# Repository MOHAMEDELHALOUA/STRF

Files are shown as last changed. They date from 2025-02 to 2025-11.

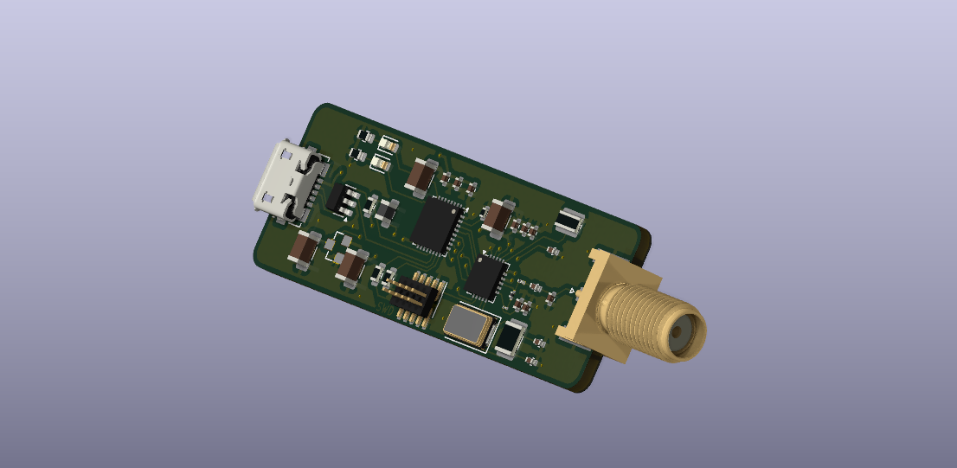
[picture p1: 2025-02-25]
STRF/finaleProduct/STRF.png

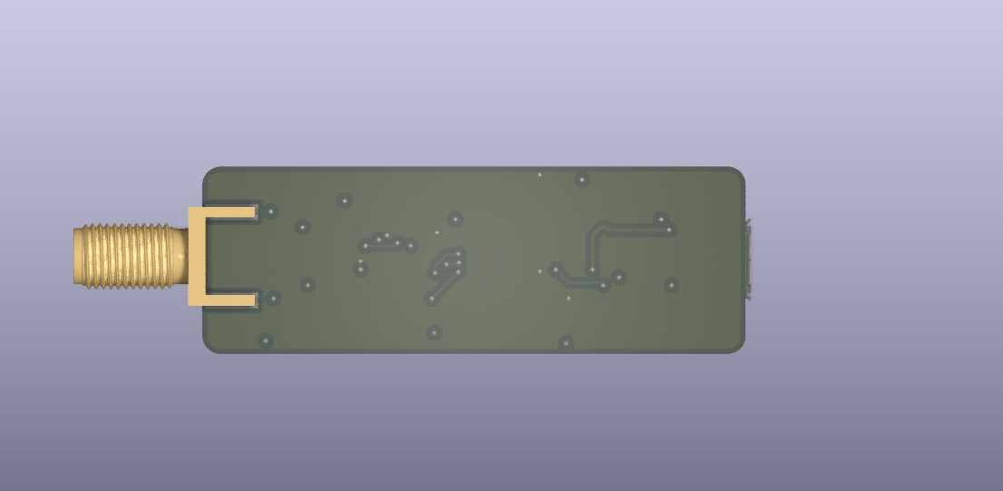
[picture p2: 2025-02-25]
STRF/finaleProduct/STRF_back.png

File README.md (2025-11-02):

# STRF
The board incorporates an STM32 microcontroller, an RF transceiver, an antenna interface, and a micro-USB full-speed interface. It is designed for various projects, such as logging data from a robot with RF capabilities. The STM32 serves as a link between the RF transceiver and a host computer via USB, and the design emphasizes compactness, measuring 15mm in height and 40mm in length.

STRF
STRF_front
STRF_back
layout1
layout2
layout3
schematic

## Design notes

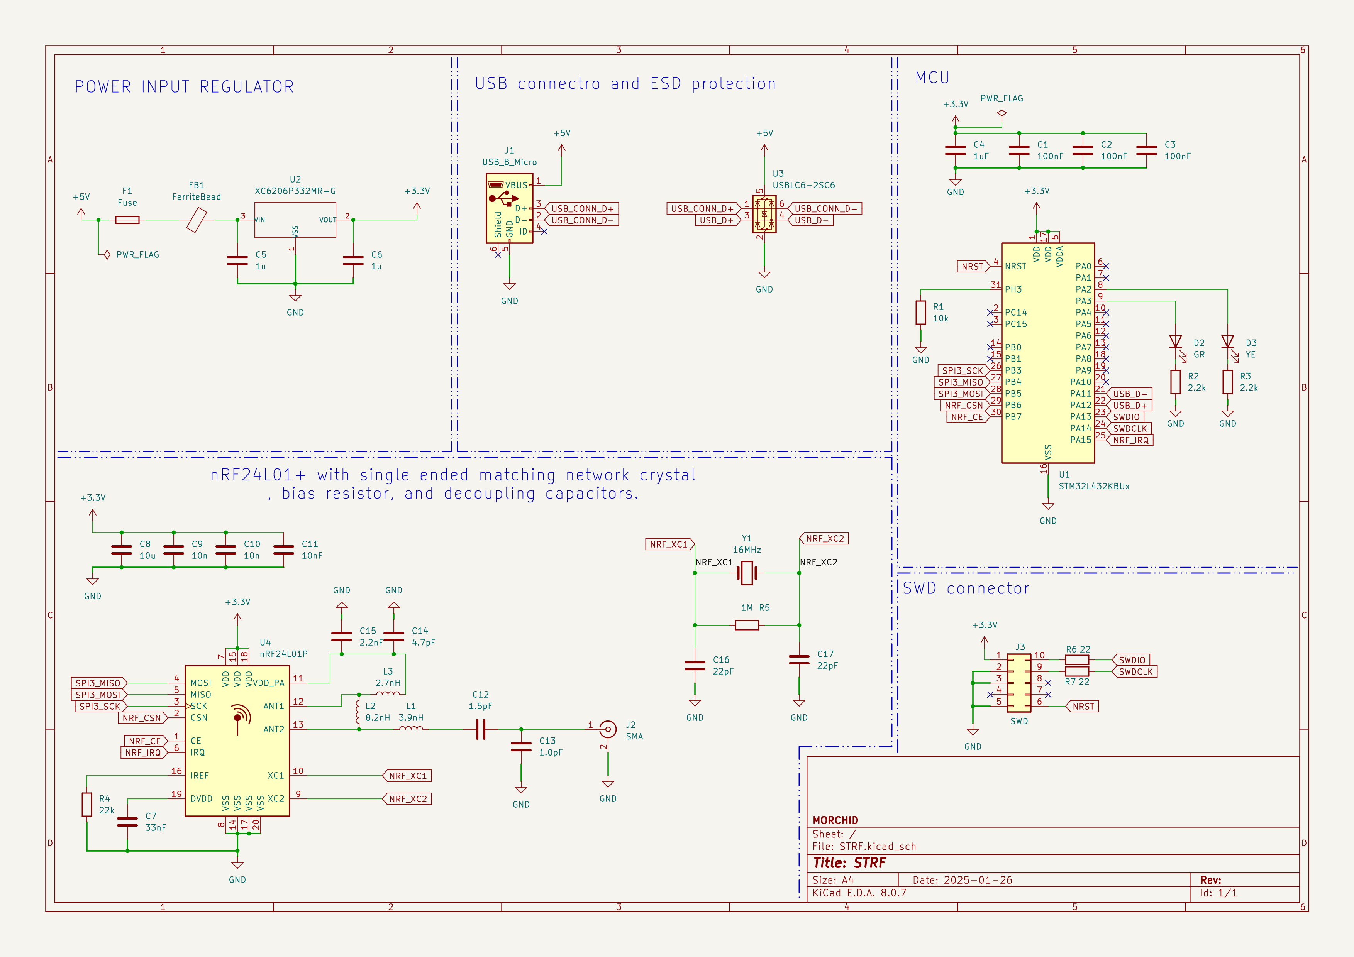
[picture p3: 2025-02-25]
STRF/finaleProduct/schematic.png

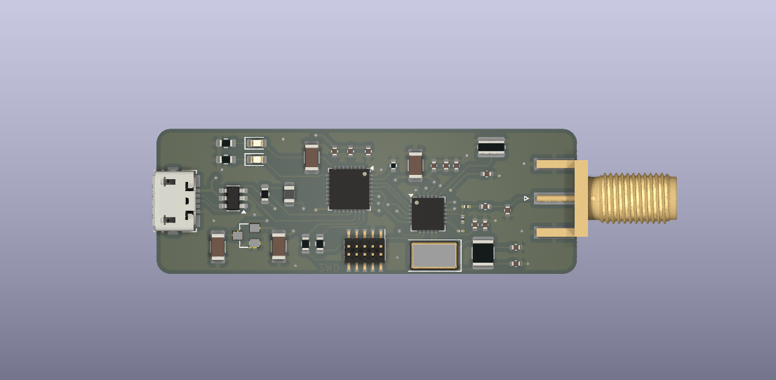
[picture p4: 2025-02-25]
STRF/finaleProduct/STRF_front.png

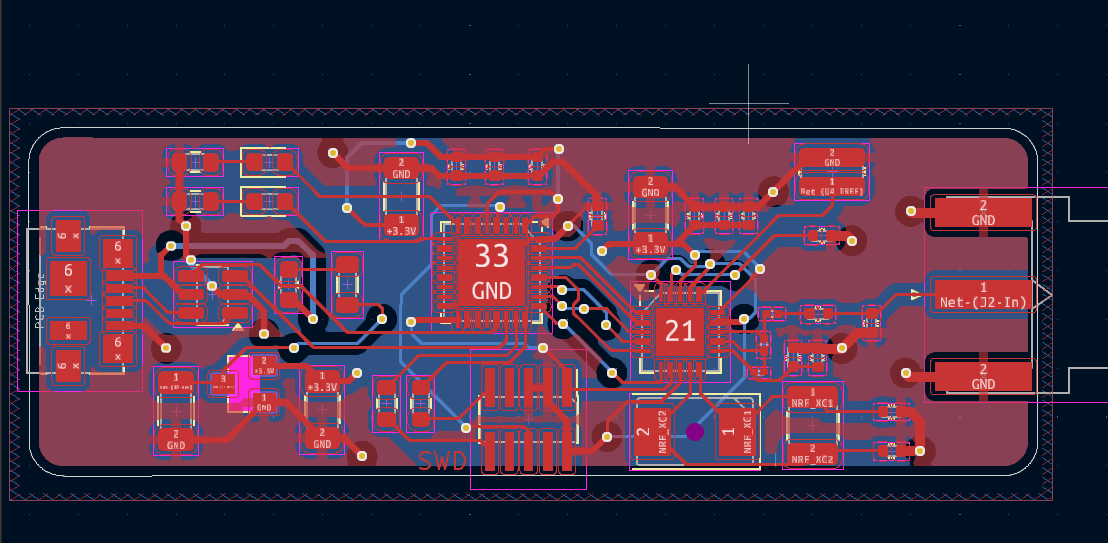
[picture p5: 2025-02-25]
STRF/finaleProduct/layout2.png

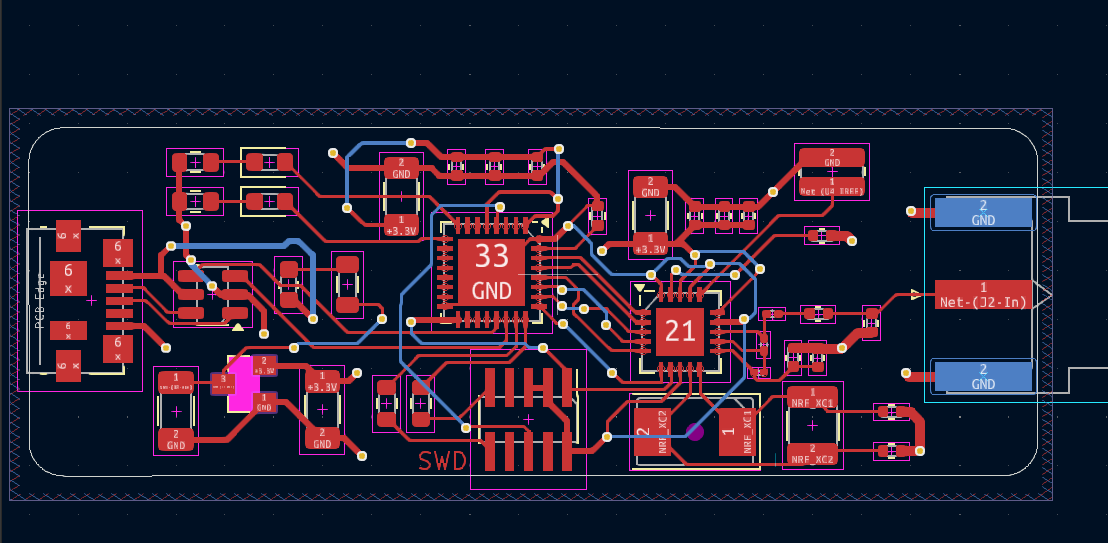
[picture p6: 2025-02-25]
STRF/finaleProduct/layout1.png

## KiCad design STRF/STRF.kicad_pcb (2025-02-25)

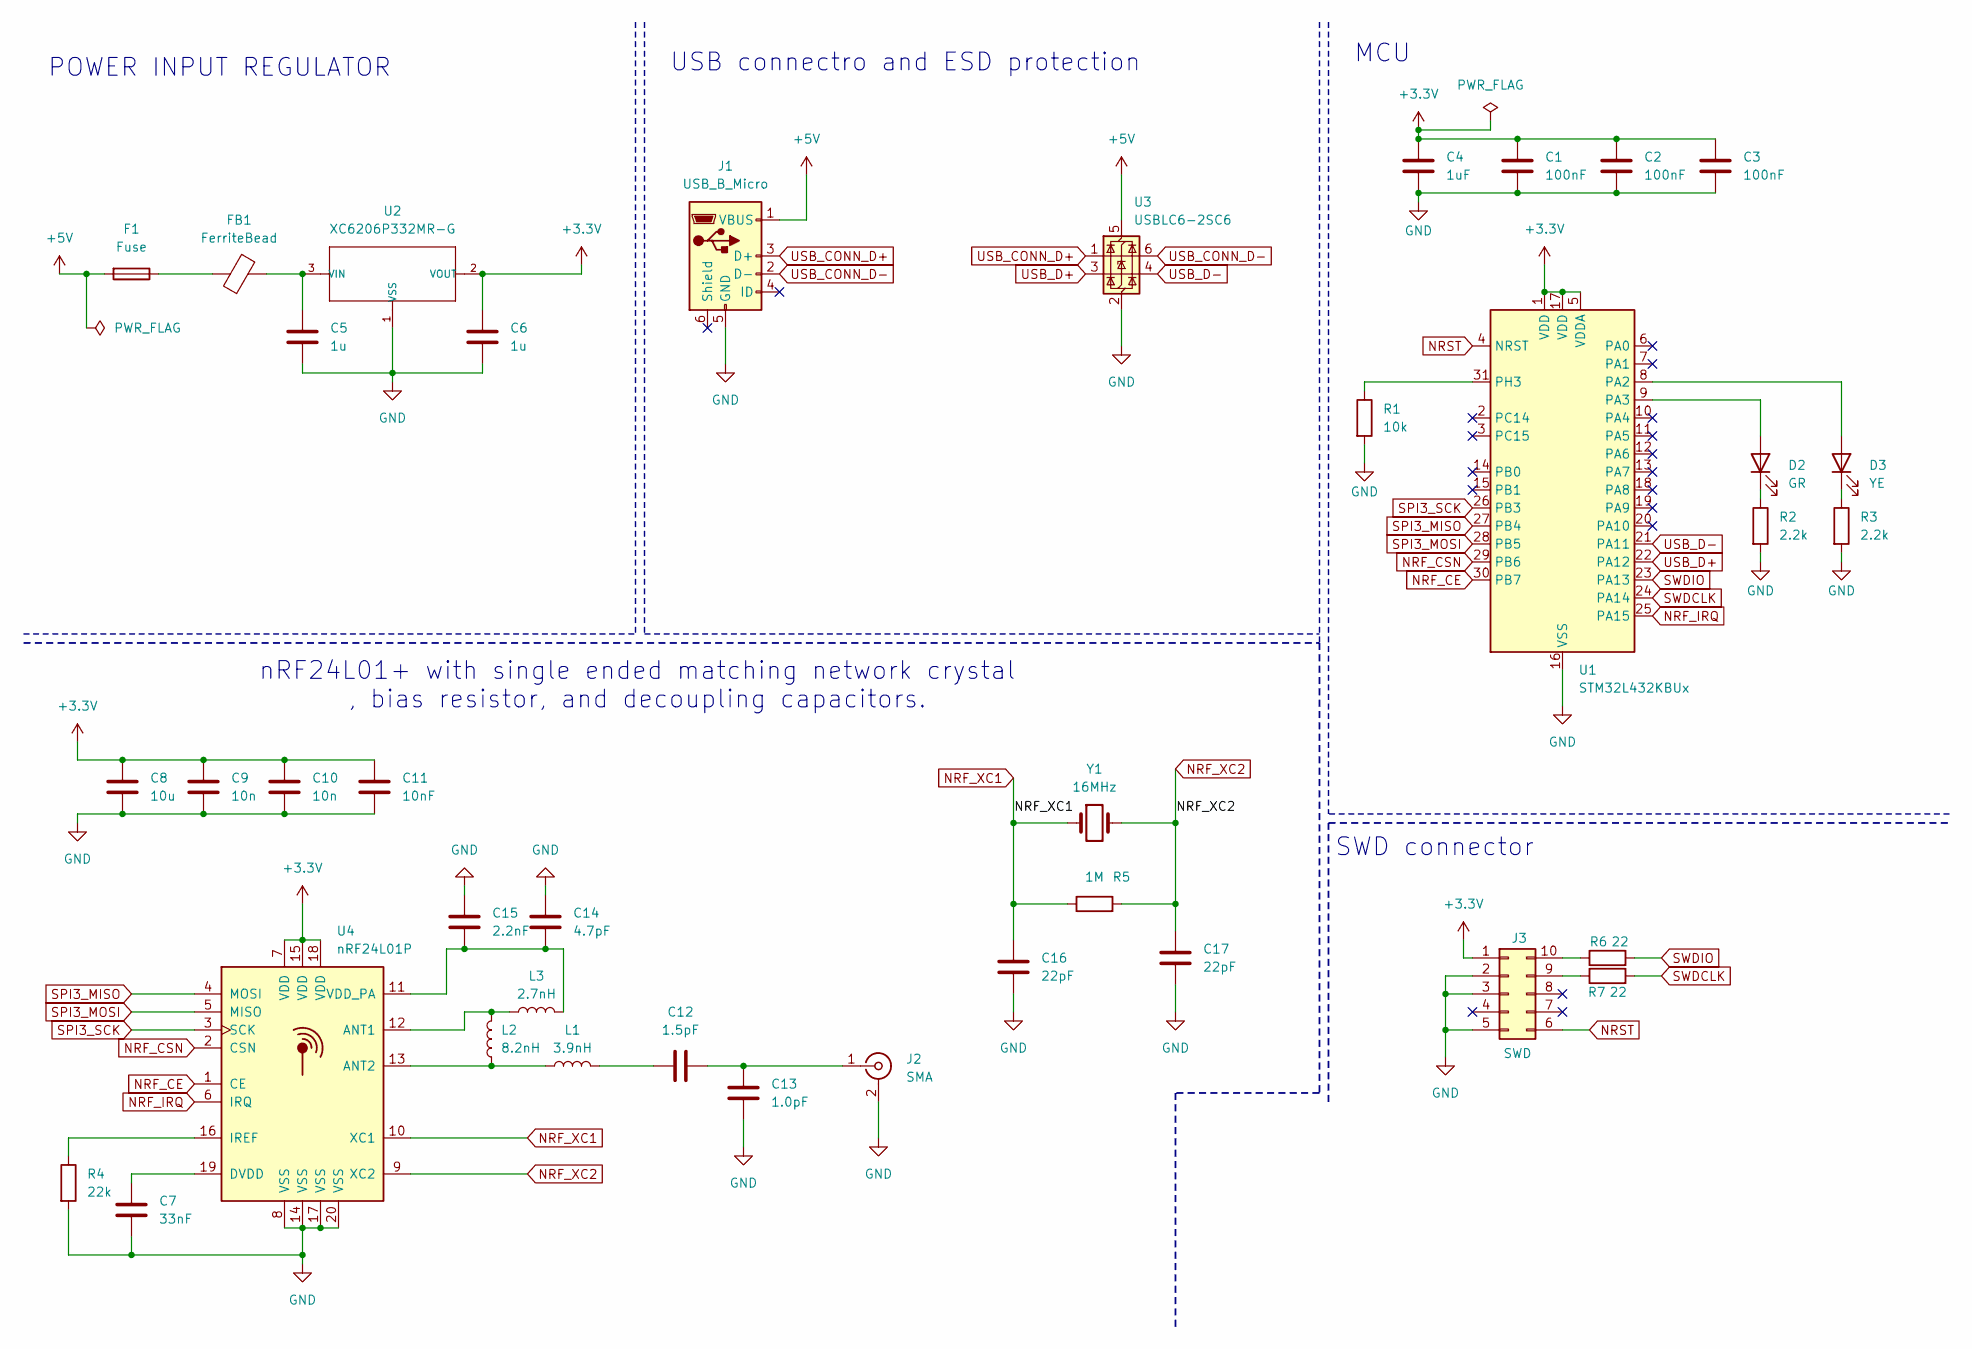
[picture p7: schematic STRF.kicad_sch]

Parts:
C1, C2, C3: 100nF; C_0402_1005Metric
C4: 1uF; C_1206_3216Metric
C5, C6: 1u; C_1206_3216Metric
C7: 33nF; C_0402_1005Metric
C8: 10u; C_1206_3216Metric
C9, C10: 10n; C_0402_1005Metric
C11: 10nF; C_0402_1005Metric
C12: 1.5pF; C_0402_1005Metric
C13: 1.0pF; C_0402_1005Metric
C14: 4.7pF; C_0402_1005Metric
C15: 2.2nF; C_0402_1005Metric
C16, C17: 22pF; C_0402_1005Metric
D2: GR; LED_0603_1608Metric
D3: YE; LED_0603_1608Metric
F1: Fuse; Fuse_0603_1608Metric
FB1: FerriteBead; L_0805_2012Metric
J1: USB_B_Micro; USB_Micro-B_Molex_47346-0001
J2: SMA; SMA_Amphenol_132289_EdgeMount
J3: SWD; PinHeader_2x05_P1.00mm_Vertical_SMD
L1: 3.9nH; L_0201_0603Metric
L2: 8.2nH; L_0201_0603Metric
L3: 2.7nH; L_01005_0402Metric
R1: 10k; R_0402_1005Metric
R2, R3: 2.2k; R_0603_1608Metric
R4: 22k; R_0612_1632Metric
R5: 1M; R_1210_3225Metric
R6, R7: 22; R_0603_1608Metric
U1: STM32L432KBUx; QFN-32-1EP_5x5mm_P0.5mm_EP3.45x3.45mm
U2: XC6206P332MR-G; SOT-23; MPN XC6206P332MR-G
U3: USBLC6-2SC6; SOT-23-6
U4: nRF24L01P; QFN-20-1EP_4x4mm_P0.5mm_EP2.5x2.5mm
Y1: 16MHz; Crystal_SMD_0603-2Pin_6.0x3.5mm

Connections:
+3.3V: C1.1, C2.1, C3.1, C4.1, C6.1, C8.1, C9.1, C10.1, C11.1, J3.1, U1.1 (VDD), U1.5 (VDDA), U1.17 (VDD), U2.2 (VOUT), U4.7 (VDD), U4.15 (VDD), U4.18 (VDD)
+5V: F1.2, J1.1 (VBUS), U3.5 (VBUS)
GND: C1.2, C2.2, C3.2, C4.2, C5.2, C6.2, C7.2, C8.2, C9.2, C10.2, C11.2, C13.1, C14.2, C15.2, C16.2, C17.2, J1.5 (GND), J2.2 (Ext), J3.2, J3.3, J3.5, R1.2, R2.2, R3.2, R4.2, U1.16 (VSS), U1.32 (VSS), U1.33 (VSS), U2.1 (VSS), U3.2 (GND), U4.8 (VSS), U4.14 (VSS), U4.17 (VSS), U4.20 (VSS)
NRF_CE: U1.30 (PB7), U4.1 (CE)
NRF_CSN: U1.29 (PB6), U4.2 (CSN)
NRF_IRQ: U1.25 (PA15), U4.6 (IRQ)
NRF_XC1: C16.1, R5.1, U4.10 (XC1), Y1.1
NRF_XC2: C17.1, R5.2, U4.9 (XC2), Y1.2
NRST: J3.6, U1.4 (NRST)
unnamed: C12.1, L1.2
unnamed: D2.2 (A), U1.9 (PA3)
unnamed: D2.1 (K), R2.1
unnamed: D3.2 (A), U1.8 (PA2)
unnamed: D3.1 (K), R3.1
unnamed: F1.1, FB1.1
unnamed: C12.2, C13.2, J2.1 (In)
unnamed: J3.9, R7.1
unnamed: J3.10, R6.1
unnamed: R1.1, U1.31 (PH3)
unnamed: C5.1, FB1.2, U2.3 (VIN)
unnamed: L2.2, L3.1, U4.12 (ANT1)
unnamed: L1.1, L2.1, U4.13 (ANT2)
unnamed: C7.1, U4.19 (DVDD)
unnamed: R4.1, U4.16 (IREF)
unnamed: C14.1, C15.1, L3.2, U4.11 (VDD_PA)
SPI3_MISO: U1.27 (PB4), U4.4 (MOSI)
SPI3_MOSI: U1.28 (PB5), U4.5 (MISO)
SPI3_SCK: U1.26 (PB3), U4.3 (SCK)
SWDCLK: R7.2, U1.24 (PA14)
SWDIO: R6.2, U1.23 (PA13)
USB_CONN_D+: J1.3 (D+), U3.1 (I/O1)
USB_CONN_D-: J1.2 (D-), U3.6 (I/O1)
USB_D+: U1.22 (PA12), U3.3 (I/O2)
USB_D-: U1.21 (PA11), U3.4 (I/O2)

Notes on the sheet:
POWER INPUT REGULATOR
SWD connector
nRF24L01+ with single ended matching network crystal , bias resistor, and decoupling capacitors.
USB connectro and ESD protection
MCU

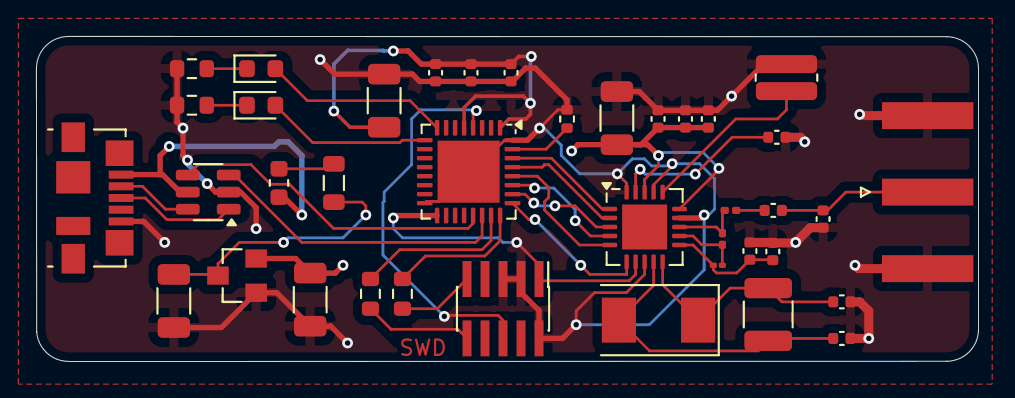
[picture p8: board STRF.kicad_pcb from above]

Board: 2 copper layers, 52.3 x 18.1 mm, 39 parts (0 on the bottom side), 34 nets.

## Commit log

2025-02-25 this is an RF board based on the stm32 mcu and nrf24l01p
    [STRF.kicad_pcb, STRF.kicad_sch]
2025-02-25 just adding a small description of the board
